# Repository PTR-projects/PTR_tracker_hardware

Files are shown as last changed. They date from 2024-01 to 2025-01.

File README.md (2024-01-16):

# PTR-Tracker hardware repository
Here you'll find the design files for the Tracker PCB

Looking for software? That's [here](https://github.com/PTR-projects/PTR_tracker_firmware)

# How to order
The folders contain the kicad projects and JLC assembly files for the 2 frequency variants of the device.

You can order the PCBs and solder them yourself, or use JLC's assembly service. Pick the frequency variant, and open the `PRODUCTION` folder. There you'll find the gerbers, BOM, and footprint positions. The only parameter you need to tick is to specify the order number location, we hid it under the GPS antenna. Don't forget to pick a color!

# Required parts
Only 1 side of the board will be soldered by JLC. You need to install an SMD dip switch, 2 0603 LEDs, a GPS antenna and an SMA connector.

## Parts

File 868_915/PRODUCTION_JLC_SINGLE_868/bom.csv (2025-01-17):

Designator | Footprint | Quantity | Value | LCSC Part #
C1 | 0402 | 1 | 470nF | C47339
C10, C14, C15, C16, C25, C26, C6 | 0402 | 7 | 100nF | C1525
C11 | 0402 | 1 | 1.5pF | C1552
C17, C18 | 0402 | 2 | 20pF | C1554
C19, C21, C9 | 0402 | 3 | 5.6pF | C1574
C2, C5, C7 | 0402 | 3 | 1uF | C52923
C20, C22, C4 | 0402 | 3 | 100pF | C1546
C3 | 0402 | 1 | 4.7uF | C23733
C8 | 0402 | 1 | 22nF | C1532
D1, D2 | 0603 | 2 | LED
FB1, FB2, FB3 | 0603 | 3 | 200mA | C1002
L1 | 0603 | 1 | 15uH | C431252
L2 | 0402 | 1 | 68nH | C391307
L3, L5, L8 | 0402 | 3 | 12nH | C275264
L4 | 0402 | 1 | 6.5nH | C778787
L6 | 0402 | 1 | 0R | C17168
L7 | 0402 | 1 | 1.3nH | C97996
R1, R11, R9 | 0402 | 3 | 50k | C25794
R10, R8 | 0402 | 2 | 1k | C11702
R12, R2, R4, R6 | 0402 | 4 | 10k | C25744
R3 | 0402 | 1 | 5k | C25905
R5 | 0402 | 1 | 100R | C25076
R7 | 0402 | 1 | 100k | C25741
SW1 | ESD103EZ | 1 | SW_DIP_x03
U1 | QFN-24-1EP_4x4mm_P0.5mm_EP2.7x2.7mm | 1 | SX1262 | C191341
U2 | SOT-23 | 1 | AP2210N-3.3TRG1 | C155508
U3 | TSSOP-20_4.4x6.5mm_P0.65mm | 1 | STM32G030F6P6 | C529330
U4 | SIM28ML | 1 | SIM28ML | C90770
U5 | QFN_6_1x1mm | 1 | SKY13453-385LF | C150878
Y1, Y2 | Crystal_SMD_2016-4Pin_2.0x1.6mm | 2 | NX2016SA-32MHZ-STD-CZS-5 | C843260

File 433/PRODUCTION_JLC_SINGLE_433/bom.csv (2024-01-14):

Designator | Footprint | Quantity | Value | LCSC Part #
AE1 | ANT1575-1540D | 1 | Antenna
BT1 | sturdy_2.54_battery_screw | 1 | Battery
C1 | 0402 | 1 | 470nF | C47339
C10, C14, C15, C16, C25, C26, C6 | 0402 | 7 | 100nF | C1525
C11 | 0402 | 1 | 4.7pF | C1569
C12 | 0402 | 1 | 1pF | C1550
C13, C9 | 0402 | 2 | 3.3pF | C1565
C17, C18 | 0402 | 2 | 20pF | C1554
C19 | 0402 | 1 | 18pF | C1549
C2, C5, C7 | 0402 | 3 | 1uF | C52923
C20, C4 | 0402 | 2 | 100pF | C1546
C21 | 0402 | 1 | 15pF | C1548
C22 | 0402 | 1 | 33pF | C1562
C23, C24 | 0402 | 2 | TBD
C3 | 0402 | 1 | 4.7uF | C23733
C8 | 0402 | 1 | 22nF | C1532
D1, D2 | 0603 | 2 | LED
FB1, FB2, FB3 | 0603 | 3 | 200mA | C1002
J1 | SMA_Samtec_SMA-J-P-X-ST-EM1_EdgeMount | 1 | Conn_Coaxial
J2 | PinHeader_1x05_P2.54mm_Vertical | 1 | Conn_01x05_Male
JP1 | SolderJumper-2_P1.3mm_Bridged_RoundedPad1.0x1.5mm | 1 | SolderJumper_2_Bridged
L1 | 0603 | 1 | 15uH | C431252
L2 | 0402 | 1 | 68nH | C391307
L3 | 0402 | 1 | 33nH | C275323
L4 | 0402 | 1 | 3.9nH | C14033
L5 | 0402 | 1 | 15nH | C27143
L6 | 0402 | 1 | 0R | C17168
R1, R11, R9 | 0402 | 3 | 50k | C25794
R10, R8 | 0402 | 2 | 1k | C11702
R12, R2, R4, R6 | 0402 | 4 | 10k | C25744
R3 | 0402 | 1 | 5k | C25905
R5 | 0402 | 1 | 100R | C25076
R7 | 0402 | 1 | 100k | C25741
SW1 | ESD103EZ | 1 | SW_DIP_x03
TP1 | TestPoint_Pad_D1.5mm | 1 | TestPoint
U1 | QFN-24-1EP_4x4mm_P0.5mm_EP2.7x2.7mm | 1 | SX1262 | C191341
U2 | SOT-23 | 1 | AP2210N-3.3TRG1 | C155508
U3 | TSSOP-20_4.4x6.5mm_P0.65mm | 1 | STM32G030F6P6 | C529330
U4 | SIM28ML | 1 | SIM28ML | C90770
U5 | QFN_6_1x1mm | 1 | SKY13453-385LF | C150878
Y1, Y2 | Crystal_SMD_2016-4Pin_2.0x1.6mm | 2 | NX2016SA-32MHZ-STD-CZS-5 | C843260

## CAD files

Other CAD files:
tracker_ptr_v2.f3d

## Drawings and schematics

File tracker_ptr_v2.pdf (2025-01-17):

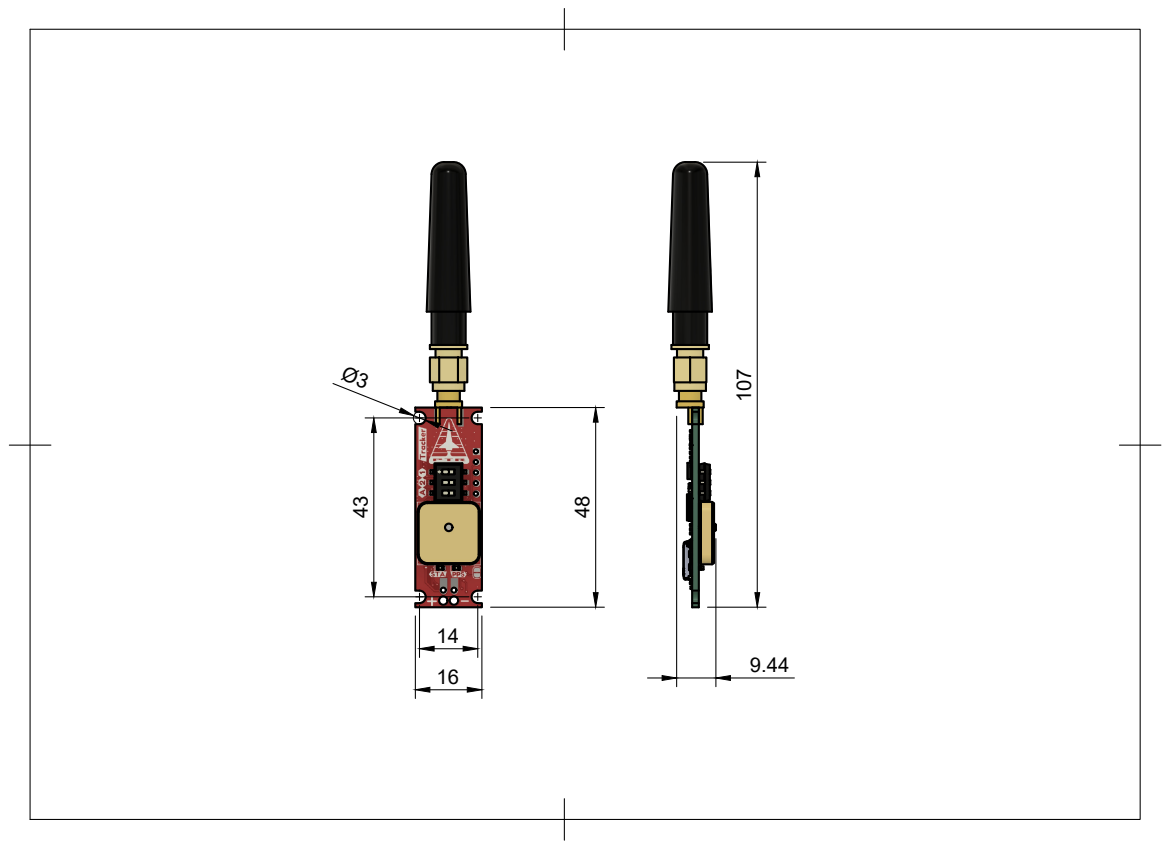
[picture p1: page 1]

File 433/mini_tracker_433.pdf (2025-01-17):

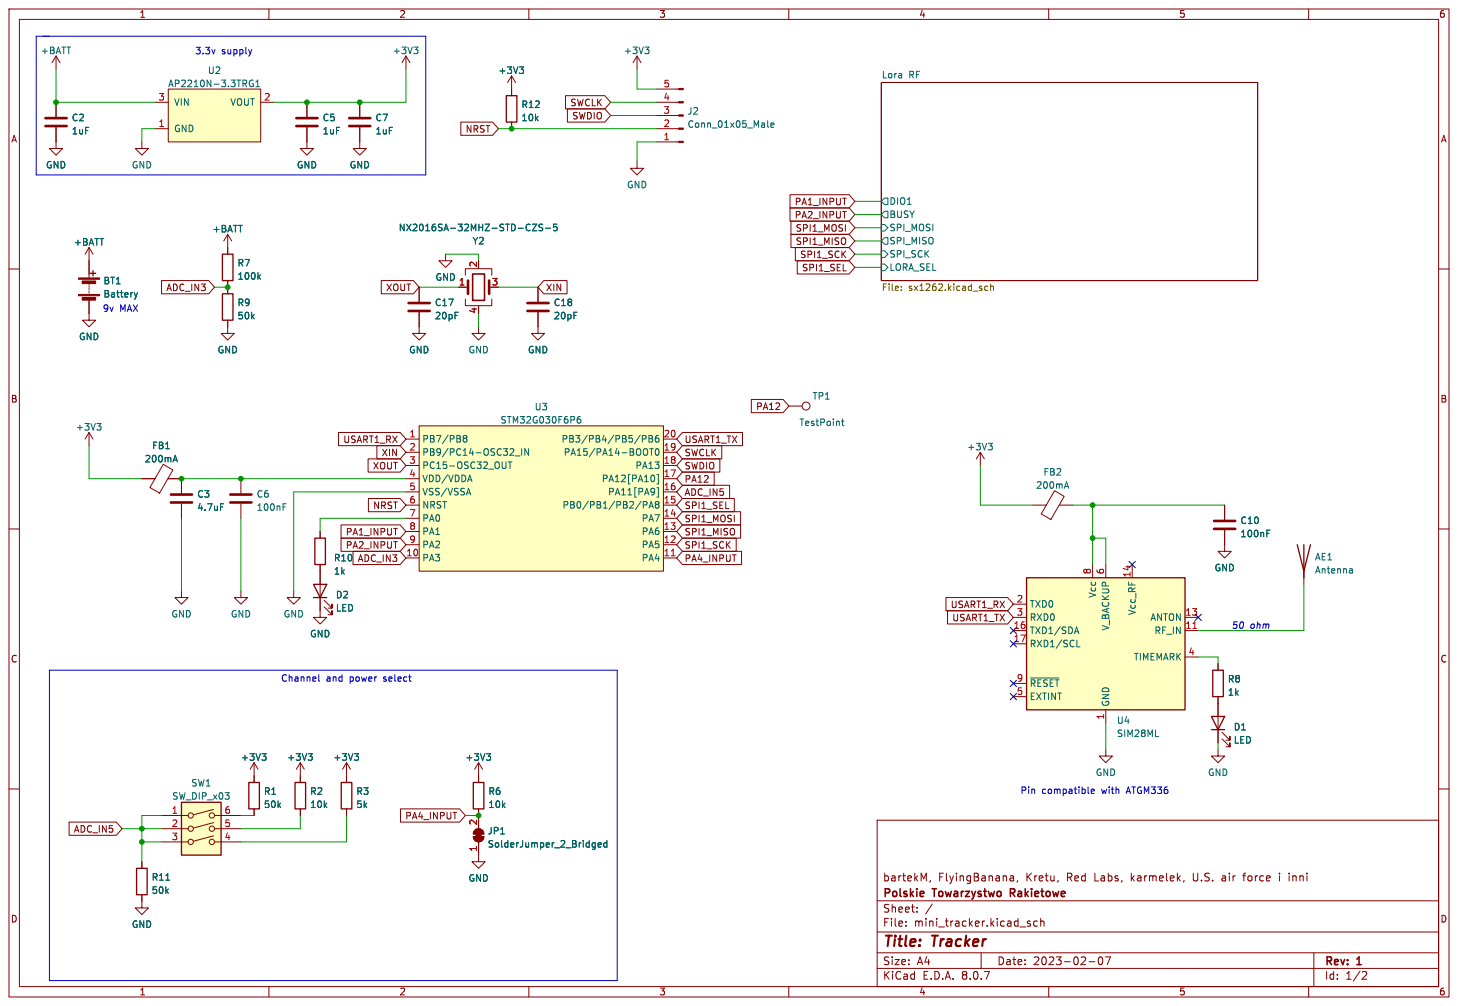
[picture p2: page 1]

1 RF_IN 11 ANTON Vcc_RF 13 14 TXD1/SDA 16 RXD1/SCL 17 TXD0 2 RXD0 3 TIMEMARK 4 EXTINT 5 V_BACKUP

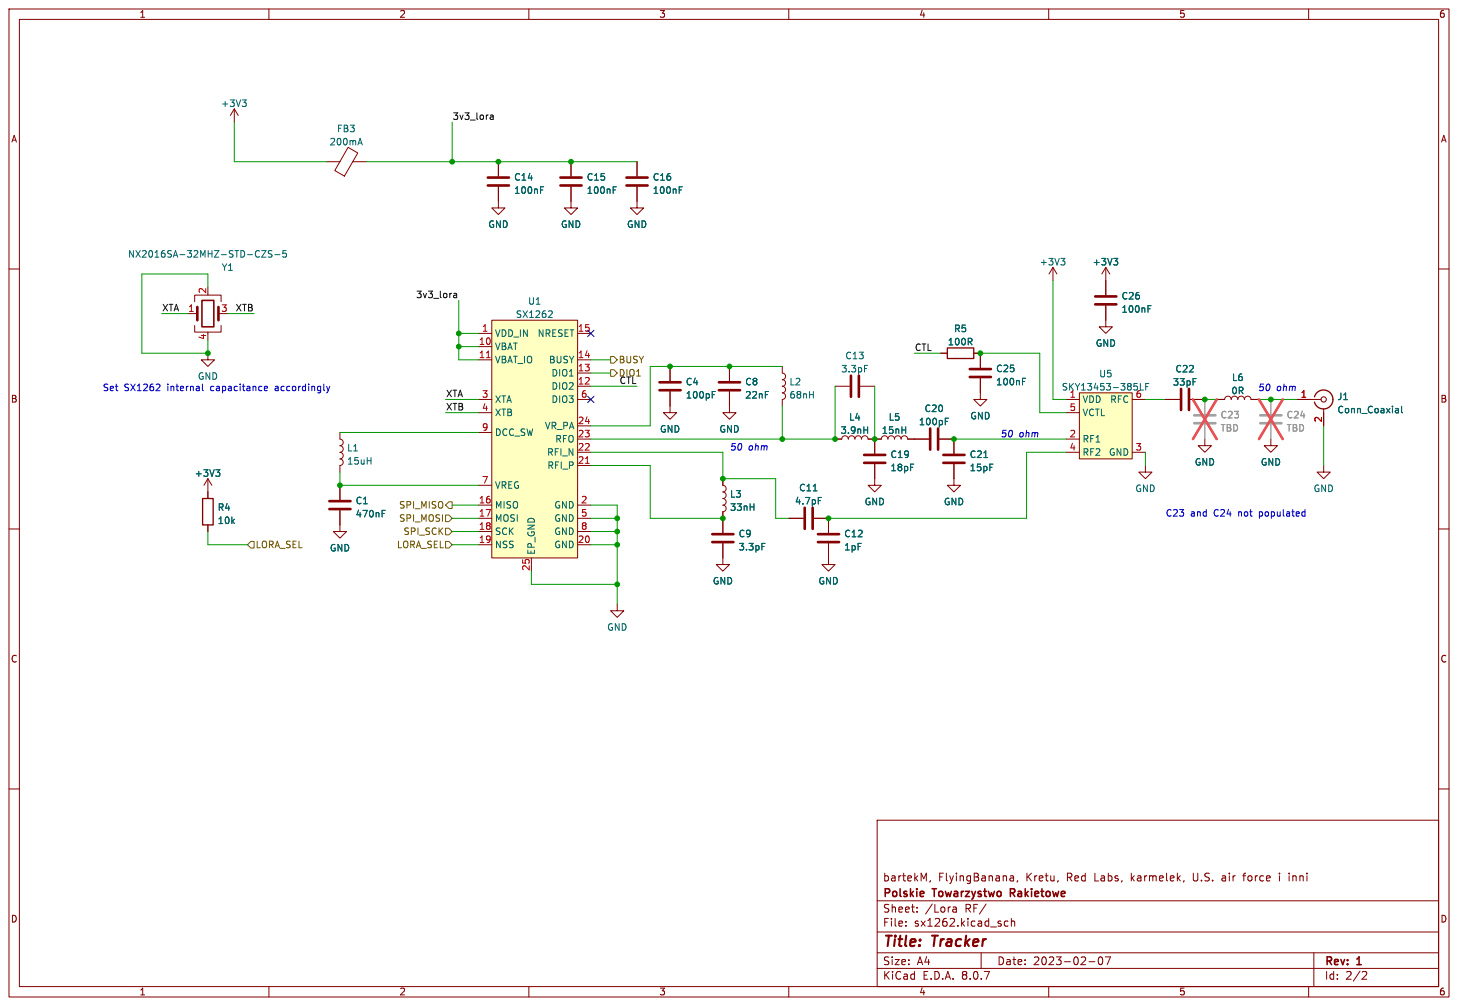
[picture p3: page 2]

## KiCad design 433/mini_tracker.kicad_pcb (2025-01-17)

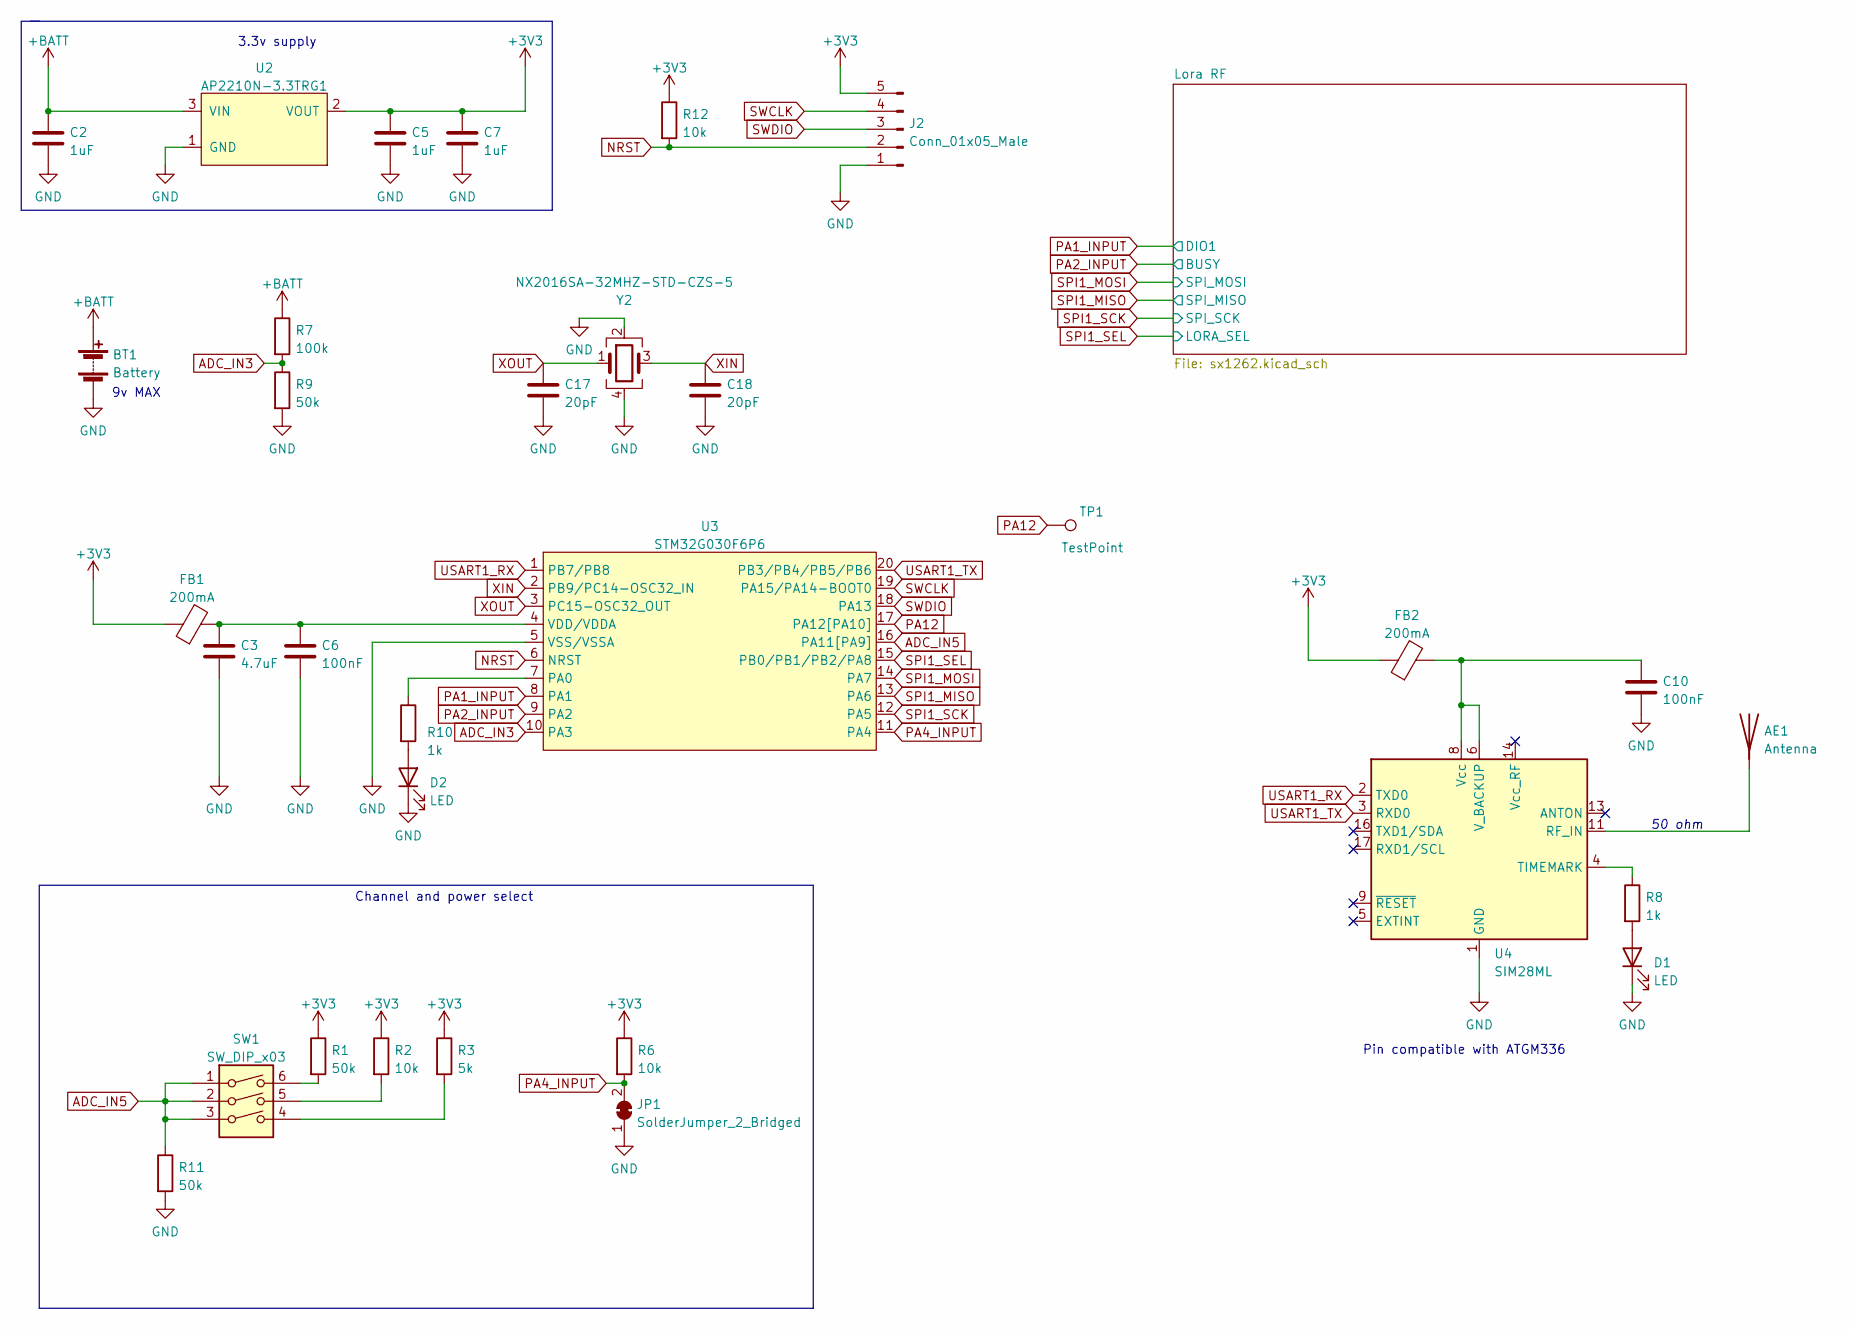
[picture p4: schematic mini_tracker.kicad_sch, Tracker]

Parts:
AE1: Antenna; ANT1575-1540D
BT1: Battery; sturdy_2.54_battery_screw
C2, C5, C7: 1uF; C_0402_1005Metric; LCSC C52923
C3: 4.7uF; C_0402_1005Metric; LCSC C23733
C6, C10: 100nF; C_0402_1005Metric; LCSC C1525
C17, C18: 20pF; C_0402_1005Metric; LCSC C1554
D1, D2: LED; LED_0603_1608Metric
FB1, FB2: 200mA; L_0603_1608Metric; LCSC C1002
J2: Conn_01x05_Male; PinHeader_1x05_P2.54mm_Vertical
JP1: SolderJumper_2_Bridged; SolderJumper-2_P1.3mm_Bridged_RoundedPad1.0x1.5mm
R1, R9, R11: 50k; R_0402_1005Metric; LCSC C25794
R2, R6, R12: 10k; R_0402_1005Metric; LCSC C25744
R3: 5k; R_0402_1005Metric; LCSC C25905
R7: 100k; R_0402_1005Metric; LCSC C25741
R8, R10: 1k; R_0402_1005Metric; LCSC C11702
SW1: SW_DIP_x03; ESD103EZ
TP1: TestPoint; TestPoint_Pad_D1.5mm
U2: AP2210N-3.3TRG1; SOT-23; LCSC C155508
U3: STM32G030F6P6; TSSOP-20_4.4x6.5mm_P0.65mm; LCSC C529330
U4: SIM28ML; LCSC C90770
Y2: NX2016SA-32MHZ-STD-CZS-5; Crystal_SMD_2016-4Pin_2.0x1.6mm; LCSC C843260

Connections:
+3V3: C5.1, C7.1, FB1.1, FB2.1, J2.5, R1.1, R2.1, R3.1, R6.1, R12.1, U2.2 (VOUT); also elsewhere on the board
+BATT: BT1.1 (+), C2.1, R7.1, U2.3 (VIN)
ADC_IN3: R7.2, R9.1, U3.10 (PA3)
ADC_IN5: R11.1, SW1.1, SW1.2, SW1.3, U3.16 (PA11[PA9])
GND: BT1.2 (-), C2.2, C3.2, C5.2, C6.2, C7.2, C10.2, C17.2, C18.2, D1.1 (K), D2.1 (K), J2.1, JP1.1 (A), R9.2, R11.2, U2.1 (GND), U3.5 (VSS/VSSA), U4.1 (GND), U4.10 (GND), U4.12 (GND), Y2.2, Y2.4; also elsewhere on the board
NRST: J2.2, R12.2, U3.6 (NRST)
unnamed: AE1.1 (A), U4.11 (RF_IN)
unnamed: D1.2 (A), R8.2
unnamed: D2.2 (A), R10.2
unnamed: R1.2, SW1.6
unnamed: R2.2, SW1.5
unnamed: R3.2, SW1.4
unnamed: R10.1, U3.7 (PA0)
unnamed: C3.1, C6.1, FB1.2, U3.4 (VDD/VDDA)
unnamed: R8.1, U4.4 (TIMEMARK)
unnamed: C10.1, FB2.2, U4.6 (V_BACKUP), U4.8 (Vcc)
PA1_INPUT: U3.8 (PA1); also elsewhere on the board
PA2_INPUT: U3.9 (PA2); also elsewhere on the board
PA4_INPUT: JP1.2 (B), R6.2, U3.11 (PA4)
PA12: TP1.1, U3.17 (PA12[PA10])
SPI1_MISO: U3.13 (PA6); also elsewhere on the board
SPI1_MOSI: U3.14 (PA7); also elsewhere on the board
SPI1_SCK: U3.12 (PA5); also elsewhere on the board
SPI1_SEL: U3.15 (PB0/PB1/PB2/PA8); also elsewhere on the board
SWCLK: J2.4, U3.19 (PA15/PA14-BOOT0)
SWDIO: J2.3, U3.18 (PA13)
USART1_RX: U3.1 (PB7/PB8), U4.2 (TXD0)
USART1_TX: U3.20 (PB3/PB4/PB5/PB6), U4.3 (RXD0)
XIN: C18.1, U3.2 (PB9/PC14-OSC32_IN), Y2.3
XOUT: C17.1, U3.3 (PC15-OSC32_OUT), Y2.1

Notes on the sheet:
3.3v supply
Channel and power select
9v MAX
50 ohm
Pin compatible with ATGM336

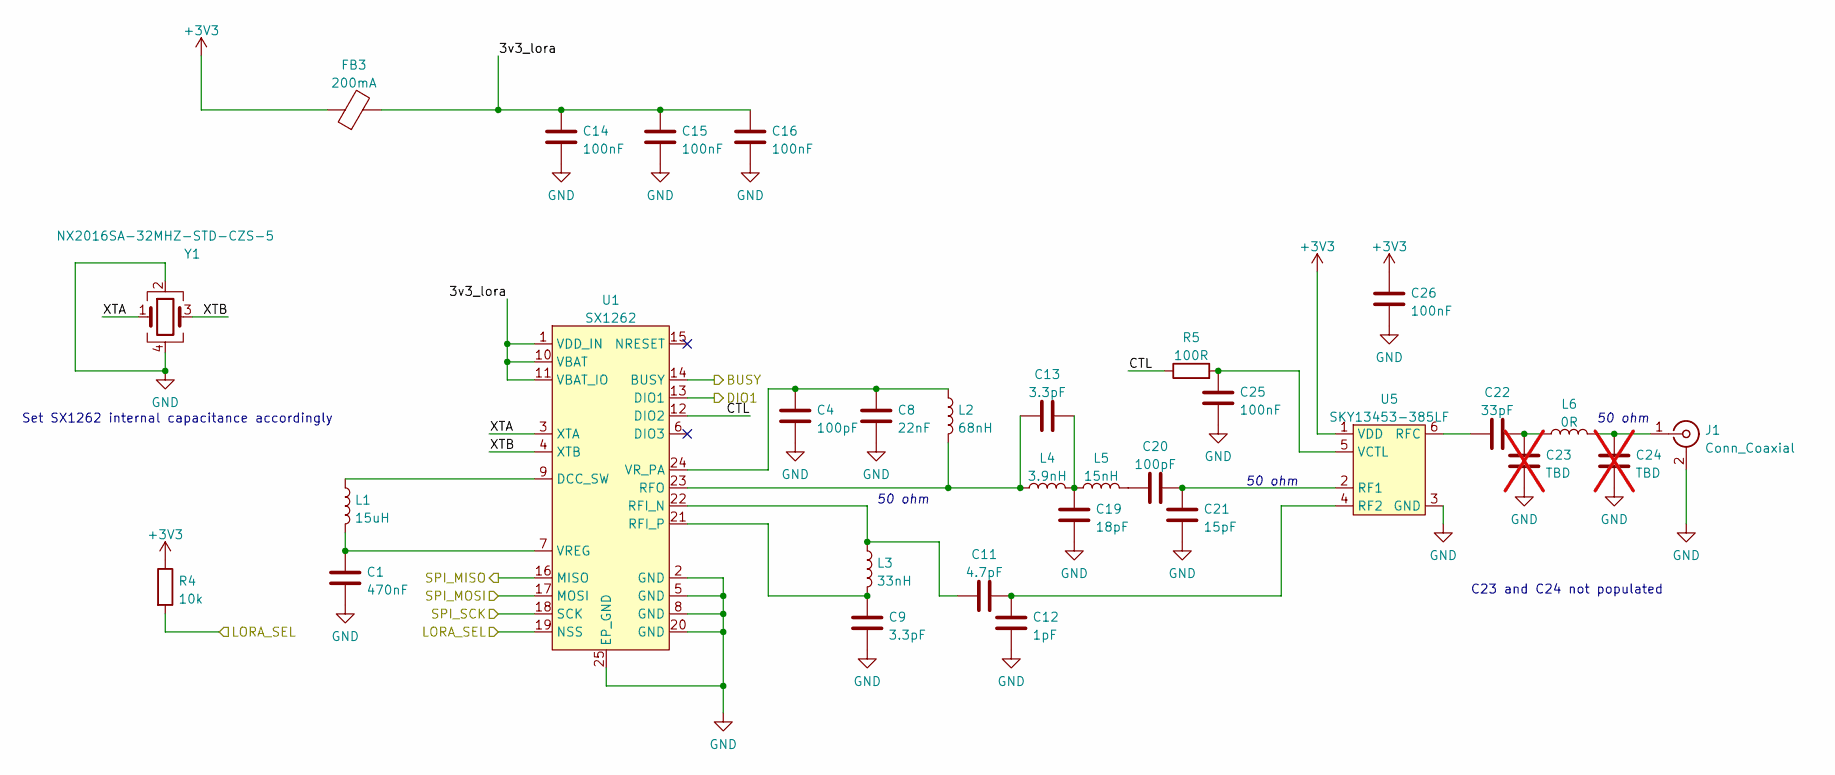
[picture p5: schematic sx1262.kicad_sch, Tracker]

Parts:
C1: 470nF; C_0402_1005Metric; LCSC C47339
C4, C20: 100pF; C_0402_1005Metric; LCSC C1546
C8: 22nF; C_0402_1005Metric; LCSC C1532
C9, C13: 3.3pF; C_0402_1005Metric; LCSC C1565
C11: 4.7pF; C_0402_1005Metric; LCSC C1569
C12: 1pF; C_0402_1005Metric; LCSC C1550
C14, C15, C16, C25, C26: 100nF; C_0402_1005Metric; LCSC C1525
C19: 18pF; C_0402_1005Metric; LCSC C1549
C21: 15pF; C_0402_1005Metric; LCSC C1548
C22: 33pF; C_0402_1005Metric; LCSC C1562
C23, C24: TBD; C_0402_1005Metric; not fitted
FB3: 200mA; L_0603_1608Metric; LCSC C1002
J1: Conn_Coaxial; SMA_Samtec_SMA-J-P-X-ST-EM1_EdgeMount
L1: 15uH; L_0603_1608Metric; LCSC C431252
L2: 68nH; L_0402_1005Metric; LCSC C391307
L3: 33nH; L_0402_1005Metric; LCSC C275323
L4: 3.9nH; L_0402_1005Metric; LCSC C14033
L5: 15nH; L_0402_1005Metric; LCSC C27143
L6: 0R; L_0402_1005Metric; LCSC C17168
R4: 10k; R_0402_1005Metric; LCSC C25744
R5: 100R; R_0402_1005Metric; LCSC C25076
U1: SX1262; QFN-24-1EP_4x4mm_P0.5mm_EP2.7x2.7mm; LCSC C191341
U5: SKY13453-385LF; QFN_6_1x1mm; LCSC C150878
Y1: NX2016SA-32MHZ-STD-CZS-5; Crystal_SMD_2016-4Pin_2.0x1.6mm; LCSC C843260

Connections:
+3V3: C26.2, FB3.1, R4.1, U5.1 (VDD); also elsewhere on the board
/Lora RF/3v3_lora: C14.1, C15.1, C16.1, FB3.2, U1.1 (VDD_IN), U1.10 (VBAT), U1.11 (VBAT_IO)
/Lora RF/CTL: R5.1, U1.12 (DIO2)
/Lora RF/XTA: U1.3 (XTA), Y1.1
/Lora RF/XTB: U1.4 (XTB), Y1.3
GND: C1.2, C4.2, C8.2, C9.1, C12.1, C14.2, C15.2, C16.2, C19.1, C21.1, C23.1, C24.1, C25.1, C26.1, J1.2 (Ext), U1.2 (GND), U1.5 (GND), U1.8 (GND), U1.20 (GND), U1.25 (EP_GND), U5.3 (GND), Y1.2, Y1.4; also elsewhere on the board
unnamed: C13.2, C19.2, L4.2, L5.1
unnamed: C20.1, L5.2
unnamed: C22.2, C23.2, L6.1
unnamed: C24.2, J1.1 (In), L6.2
unnamed: L1.1, U1.9 (DCC_SW)
unnamed: C11.1, L3.1, U1.22 (RFI_N)
unnamed: C9.2, L3.2, U1.21 (RFI_P)
unnamed: C13.1, L2.2, L4.1, U1.23 (RFO)
unnamed: C1.1, L1.2, U1.7 (VREG)
unnamed: C4.1, C8.1, L2.1, U1.24 (VR_PA)
unnamed: C20.2, C21.2, U5.2 (RF1)
unnamed: C11.2, C12.2, U5.4 (RF2)
unnamed: C22.1, U5.6 (RFC)
unnamed: C25.2, R5.2, U5.5 (VCTL)
PA1_INPUT: U1.13 (DIO1); also elsewhere on the board
PA2_INPUT: U1.14 (BUSY); also elsewhere on the board
SPI1_MISO: U1.16 (MISO); also elsewhere on the board
SPI1_MOSI: U1.17 (MOSI); also elsewhere on the board
SPI1_SCK: U1.18 (SCK); also elsewhere on the board
SPI1_SEL: R4.2, U1.19 (NSS); also elsewhere on the board

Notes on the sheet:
Set SX1262 internal capacitance accordingly
50 ohm
C23 and C24 not populated

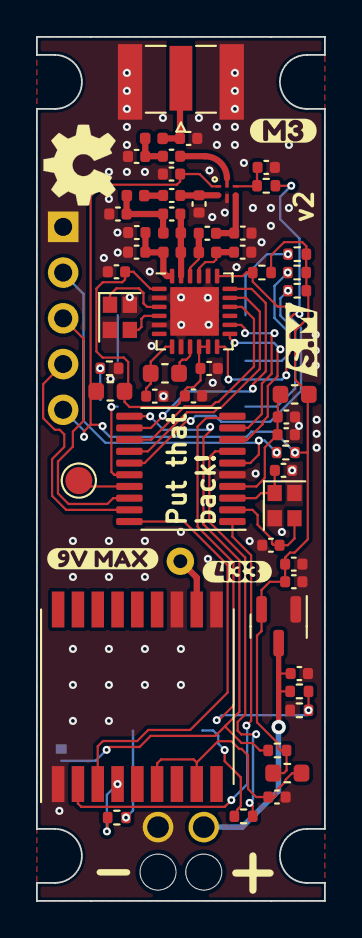
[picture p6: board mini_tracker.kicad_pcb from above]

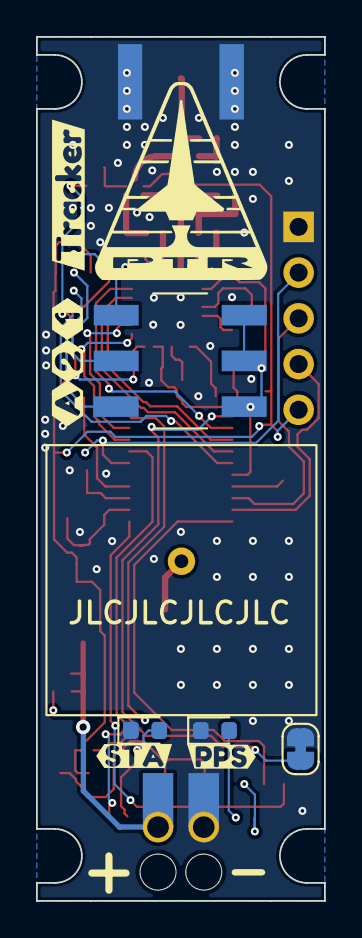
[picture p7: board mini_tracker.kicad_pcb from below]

Board: 2 copper layers, 16.0 x 48.0 mm, 73 parts (13 on the bottom side), 48 nets.

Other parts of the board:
kibuzzard-63C2A8A3: G***; kibuzzard-63C2A8A3
kibuzzard-63C2A895: G***; kibuzzard-63C2A895
kibuzzard-65A3B6E4: G***; kibuzzard-65A3B6E4
kibuzzard-65ED941B: G***; kibuzzard-65ED941B
kibuzzard-65ED9408: G***; kibuzzard-65ED9408
kibuzzard-640F0FCE: G***; kibuzzard-640F0FCE
kibuzzard-640F1272: G***; kibuzzard-640F1272
kibuzzard-6408E8C9: G***; kibuzzard-6408E8C9
kibuzzard-65194BBF: G***; kibuzzard-65194BBF
kibuzzard-64020663: G***; kibuzzard-64020663

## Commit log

2024-01-14 Tracker V2 433
    V2 of the tracker, 433MHz version
    [mini_tracker.kicad_pcb, mini_tracker.kicad_sch, sx1262.kicad_sch]
2024-01-14 Tracker V2 868
    V2 of the tracker, 868/915MHz broadband version
    [mini_tracker.kicad_pcb, mini_tracker.kicad_sch, sx1262.kicad_sch]
2024-01-14 cleanup and rename old files
    [mini_tracker.kicad_pcb]
2024-01-14 Update gitignore
    now include SMT assembly files
2024-01-14 SMT assembly files
    [bom.csv, designators.csv, positions.csv]
2025-01-17 Update production files
    -Fixed sta and pps label swap for both versions
    -Completely redesign passive network for 868 version for lower extended components fee
    [bom.csv, designators.csv, mini_tracker.kicad_pcb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]
